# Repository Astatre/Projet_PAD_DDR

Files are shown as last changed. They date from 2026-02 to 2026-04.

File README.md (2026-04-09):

# Projet_PAD_DDR

## Description

Le projet **Projet_PAD_DDR** vise à développer un pad de jeu personnalisé, intégrant à la fois les composants matériels (hardware) et logiciels (software) nécessaires à sa réalisation. Ce pad est conçu pour être utilisé dans des jeux de rythme ou d'autres applications interactives, offrant une expérience de jeu immersive et personnalisable.

## Objectifs

- Concevoir et assembler le hardware du pad, incluant des boutons et interfaces de connexion.
- Développer le software pour gérer les entrées utilisateur, traiter les signaux et communiquer avec des appareils externes (comme un ordinateur ou une console de jeu).

## Cahier des Charges

### Fonctionnalités Requises
- **Hardware** :
    - Boutons résistants et sensibles pour une détection précise des pressions.
    - Interface de connexion USB pour une intégration facile.
    - Alimentation via câble.
- **Software** :
    - Gestion des entrées en temps réel.
    - Compatibilité avec des systèmes d'exploitation courants (Windows, Linux).

### Contraintes
- Facilité d'assemblage et de maintenance.
- Respect de l'environnement.

## Structure du Projet

- **Hardware** : Schémas et composants.
- **Software** : Code source, bibliothèques et exemples d'utilisation.
- **Modèles 3D** : Ensemble des modèles d'interrupteurs pour permettre un ajustement personnalisé.

## Installation et Utilisation

1. **Matériel** : Créer le PCB présent dans le dossier `Kicad`. (V2 : connexion USB Micro, V3 : connexion USB-C)
2. **PAD** : Suivre les différents schémas et utiliser les différents modèles pour les interrupteurs dans le dossier `Model`.
3. **Logiciel** : Cloner le dépôt et compiler le code selon les instructions dans le dossier `Cube Workspace`.
4. **Test** : Connecter le pad à votre appareil et tester les fonctionnalités.

## Contribution

Les contributions sont les bienvenues ! Veuillez soumettre des issues ou des pull requests pour améliorer le projet.

## Licence

Ce projet est sous licence [MIT](https://opensource.org/licenses/MIT).

## Auteurs

- [Drault, Sourbé, Sayavong, Dalmon] - Développeurs principaux

Pour plus d'informations, consultez les fichiers dans le dépôt.

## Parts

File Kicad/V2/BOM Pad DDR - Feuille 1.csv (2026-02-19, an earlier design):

Name | Value | Socket | Nb | Data
Resistance | 100k | 0805 | 3 | Resistance.pdf
Resistance | 4.7k | 0805 | 5 | Resistance.pdf
Resistance | 290 | 0805 | 1 | Resistance.pdf
Resistance | 140 | 0805 | 1 | Resistance.pdf
Resistance | 120 | 0805 | 1 | Resistance.pdf
Resistance | 100 | 0805 | 1 | Resistance.pdf
Resistance | R_des_cables | 0805 | 8 | Resistance.pdf
Capacitor | 1µF | 0805 | 3 | Capacitor.pdf
Capacitor | 20pF | 0805 | 2 | Capacitor.pdf
Capacitor | 100nF | 0805 | 6 | Capacitor.pdf
Capacitor | 4.7µF | 0805 | 1 | Capacitor.pdf
Capacitor | C_cable | 0805 | 4 | Capacitor.pdf
LED | Vert | 0805 | 2 | https://www.farnell.com/datasheets/2045828.pdf
LED | Rouge | 0805 | 1 | https://www.farnell.com/datasheets/2045967.pdf
USB_B_Micro | NA | Wuerth_629105150521 | 1
SWD | 2 x 7 | 1.27 mm | 1
JST | 1 x2 | 2.50 mm | 4 | ST_XH_B2B-XH-A
Pin test | 1 x 8 | 2.54 mm | 1
Pin test | 1 x 2 | 2.54 mm | 2
Transistor | BCX56 | SOT-233 | 1 | https://www.mouser.fr/datasheet/3/70/1/bcp54_bcp55_bcp56.pdf
STM | G431K6Tx | LQFP-32_7x7mm_P0.8mm | 1 | https://www.st.com/resource/en/datasheet/stm32g431k6.pdf
Cristal | 32.768kHz | 1.5 x 3.2 | 1 | 830 054 236
Regulateur | 5 / 3.3 V | SSOP5 | 1 | https://moodle.ensea.fr/pluginfile.php/10188/mod_folder/content/0/BU33SD5WG-TR.pdf?forcedownload=1
Buton | NA | 6.2 x 6.2 | 2 | https://www.we-online.com/components/products/datasheet/430182070816.pdf

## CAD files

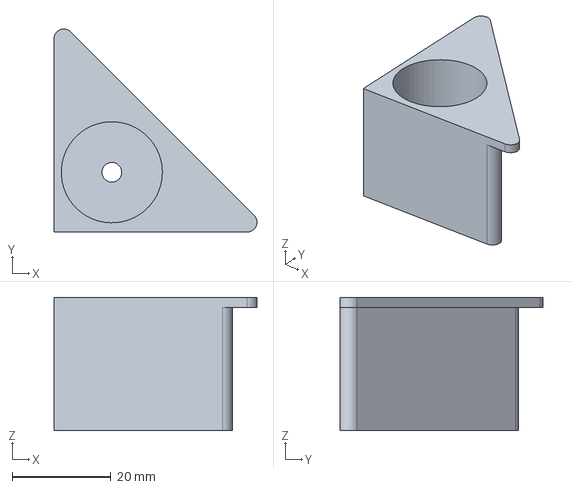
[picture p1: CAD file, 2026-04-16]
Modèles/Brackets/Brackets.FCStd
41.2 x 41.2 x 27.0 mm

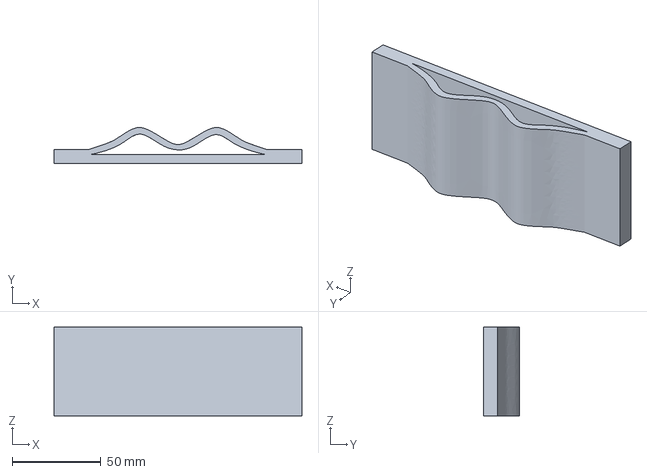
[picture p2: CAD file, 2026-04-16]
Modèles/Interrupteurs/springalt-Body.3mf
140.0 x 20.4 x 50.0 mm

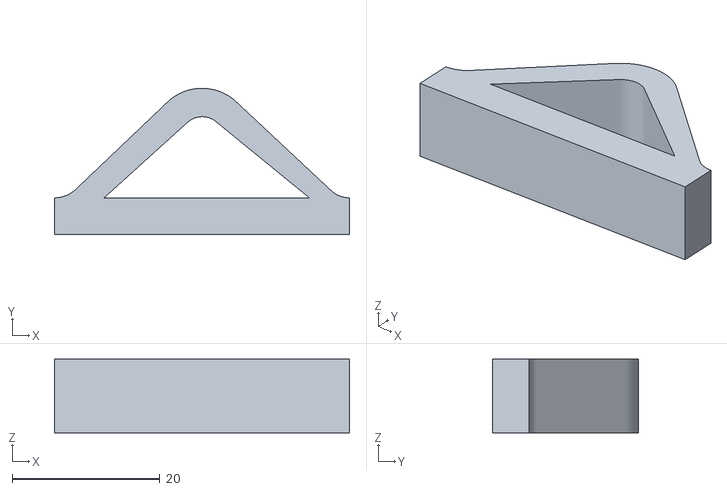
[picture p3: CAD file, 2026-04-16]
Modèles/Support coin/Support coin-Corps.stl
40.0 x 19.9 x 10.0

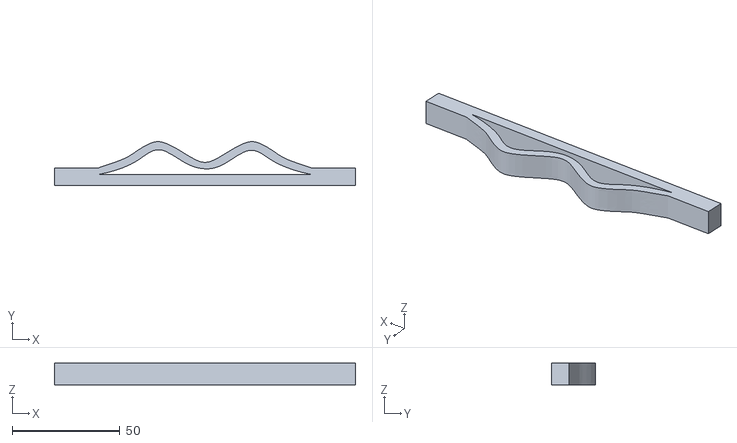
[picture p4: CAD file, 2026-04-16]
Modèles/Interrupteurs/Spring-v1.stl
140.0 x 20.4 x 10.0

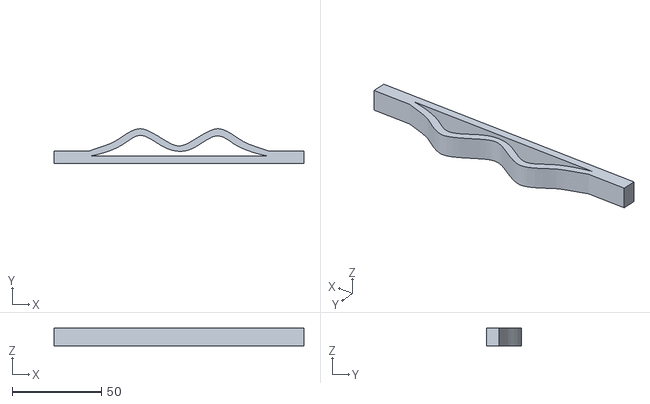
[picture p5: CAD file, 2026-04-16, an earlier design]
Modèles/Interrupteurs/Spring-v0.stl
140.0 x 19.4 x 10.0

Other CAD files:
Modèles/Support coin/Support coin.FCStd
Modèles/Interrupteurs/springalt.FCStd

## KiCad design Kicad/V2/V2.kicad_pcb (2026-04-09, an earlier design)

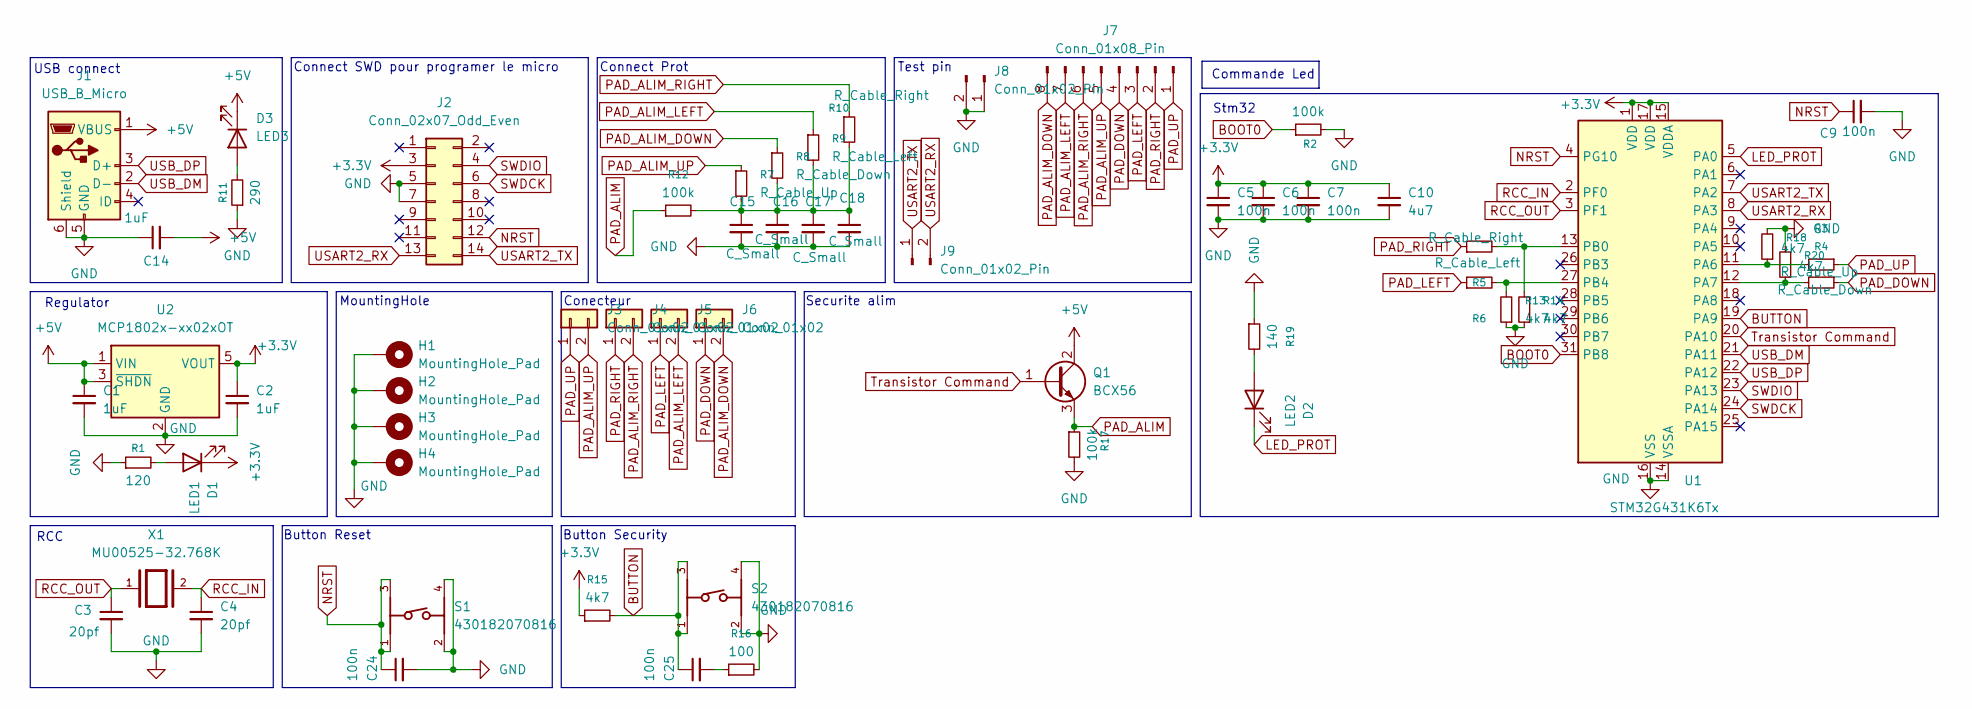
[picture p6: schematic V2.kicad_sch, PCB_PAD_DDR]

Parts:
C1, C2, C14: 1uF; C_0805_2012Metric_Pad1.18x1.45mm_HandSolder
C3, C4: 20pf; C_0805_2012Metric_Pad1.18x1.45mm_HandSolder
C5, C6, C7, C9, C24, C25: 100n; C_0805_2012Metric_Pad1.18x1.45mm_HandSolder
C10: 4u7; C_0805_2012Metric_Pad1.18x1.45mm_HandSolder
C15, C16, C17, C18: C_Small; C_0805_2012Metric_Pad1.18x1.45mm_HandSolder
D1: LED1; LED_0805_2012Metric_Pad1.15x1.40mm_HandSolder
D2: LED2; LED_0805_2012Metric_Pad1.15x1.40mm_HandSolder
D3: LED3; LED_0805_2012Metric_Pad1.15x1.40mm_HandSolder
H1, H2, H3, H4: MountingHole_Pad; MountingHole_3.2mm_M3_DIN965_Pad
J1: USB_B_Micro; USB_Micro-B_Wuerth_629105150521
J2: Conn_02x07_Odd_Even; PinHeader_2x07_P1.27mm_Vertical_SMD
J3, J4, J5, J6: Conn_01x02; JST_XH_B2B-XH-A_1x02_P2.50mm_Vertical
J7: Conn_01x08_Pin; PinHeader_1x08_P2.54mm_Vertical
J8, J9: Conn_01x02_Pin; PinHeader_1x02_P2.54mm_Vertical
Q1: BCX56; SOT-223
R1: 120; R_0805_2012Metric_Pad1.20x1.40mm_HandSolder
R2, R12, R17: 100k; R_0805_2012Metric_Pad1.20x1.40mm_HandSolder
R3, R7: R_Cable_Up; R_0805_2012Metric_Pad1.20x1.40mm_HandSolder
R4, R8: R_Cable_Down; R_0805_2012Metric_Pad1.20x1.40mm_HandSolder
R5, R10: R_Cable_Right; R_0805_2012Metric_Pad1.20x1.40mm_HandSolder
R6, R9: R_Cable_Left; R_0805_2012Metric_Pad1.20x1.40mm_HandSolder
R11: 290; R_0805_2012Metric_Pad1.20x1.40mm_HandSolder
R13, R14, R15, R18, R20: 4k7; R_0805_2012Metric_Pad1.20x1.40mm_HandSolder
R16: 100; R_0805_2012Metric_Pad1.20x1.40mm_HandSolder
R19: 140; R_0805_2012Metric_Pad1.20x1.40mm_HandSolder
S1, S2: 430182070816
U1: STM32G431K6Tx; LQFP-32_7x7mm_P0.8mm
U2: MCP1802x-xx02xOT; SOT-23-5
X1: MU00525-32.768K; XTAL_MU00525-32.768K

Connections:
Transistor Command: Q1.1 (B), U1.20 (PA10)
+3.3V: C2.1, C5.1, C6.1, C7.1, C10.1, D1.1 (K), J2.3, R15.1, U1.1 (VDD), U1.15 (VDDA), U1.17 (VDD), U2.5 (VOUT)
+5V: C1.1, C14.2, D3.1 (K), J1.1 (VBUS), Q1.2 (C), U2.1 (VIN), U2.3 (~SHDN)
BOOT0: R2.1, U1.31 (PB8)
BUTTON: C25.1, R15.2, S2.1, S2.3, U1.19 (PA9)
GND: C1.2, C2.2, C3.2, C4.2, C5.2, C6.2, C7.2, C9.2, C10.2, C14.1, C15.2, C16.2, C17.2, C18.2, C24.2, H1.1, H2.1, H3.1, H4.1, J1.5 (GND), J1.6 (Shield), J2.5, J2.7, J8.1, J8.2, R1.1, R2.2, R11.1, R13.1, R14.1, R16.2, R17.2, R18.2, R19.1, R20.2, S1.2, S1.4, S2.2, S2.4, U1.14 (VSSA), U1.16 (VSS), U1.32 (VSS), U2.2 (GND)
LED_PROT: D2.1 (K), U1.5 (PA0)
NRST: C9.1, C24.1, J2.12, S1.1, S1.3, U1.4 (PG10)
unnamed: C15.1, C16.1, C17.1, C18.1, R7.2, R8.2, R9.2, R10.2, R12.2
unnamed: C25.2, R16.1
unnamed: D1.2 (A), R1.2
unnamed: D2.2 (A), R19.2
unnamed: D3.2 (A), R11.2
unnamed: R3.2, R18.1, U1.11 (PA6)
unnamed: R4.2, R20.1, U1.12 (PA7)
unnamed: R5.2, R14.2, U1.13 (PB0)
unnamed: R6.2, R13.2, U1.27 (PB4)
PAD_ALIM: Q1.3 (E), R12.1, R17.1
PAD_ALIM_DOWN: J6.2, J7.8, R8.1
PAD_ALIM_LEFT: J5.2, J7.7, R9.1
PAD_ALIM_RIGHT: J4.2, J7.6, R10.1
PAD_ALIM_UP: J3.2, J7.5, R7.1
PAD_DOWN: J6.1, J7.4, R4.1
PAD_LEFT: J5.1, J7.3, R6.1
PAD_RIGHT: J4.1, J7.2, R5.1
PAD_UP: J3.1, J7.1, R3.1
RCC_IN: C4.1, U1.2 (PF0), X1.2
RCC_OUT: C3.1, U1.3 (PF1), X1.1
SWDCK: J2.6, U1.24 (PA14)
SWDIO: J2.4, U1.23 (PA13)
USART2_RX: J2.13, J9.2, U1.8 (PA3)
USART2_TX: J2.14, J9.1, U1.7 (PA2)
USB_DM: J1.2 (D-), U1.21 (PA11)
USB_DP: J1.3 (D+), U1.22 (PA12)

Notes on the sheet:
Securite alim
Regulator
Commande Led
MountingHole
Stm32
Test pin
USB connect
Connect SWD pour programer le micro
Button Security
Button Reset
RCC
Conecteur
Connect Prot

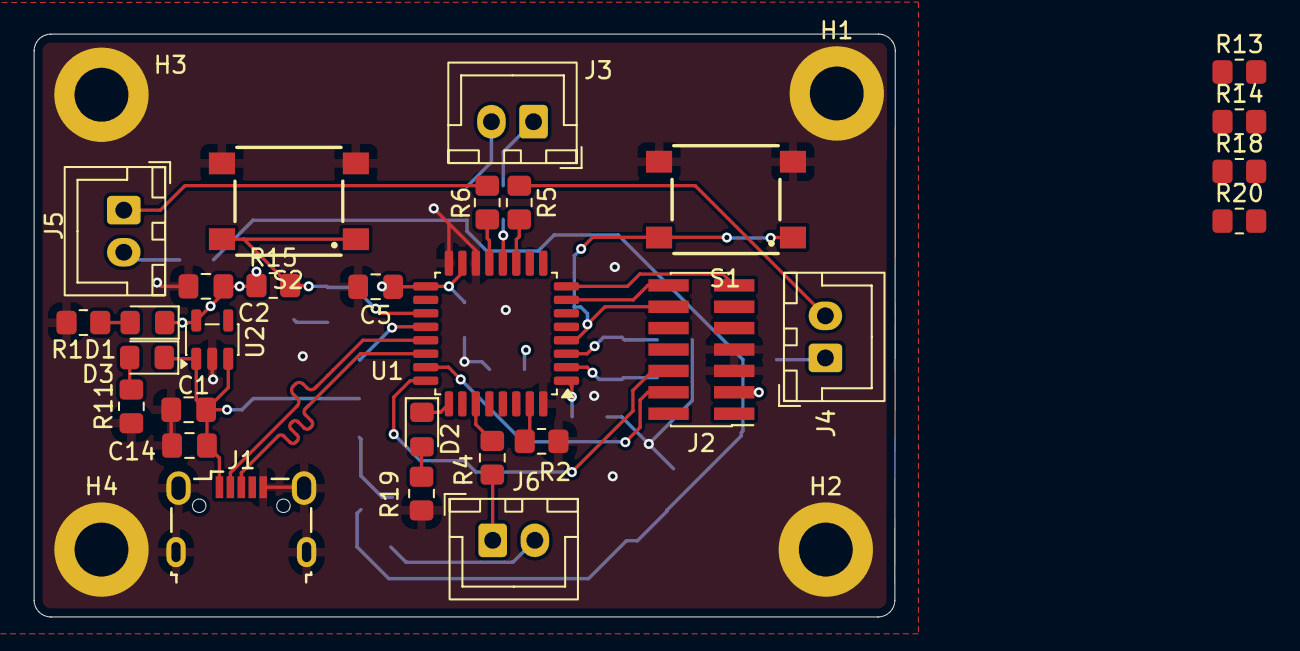
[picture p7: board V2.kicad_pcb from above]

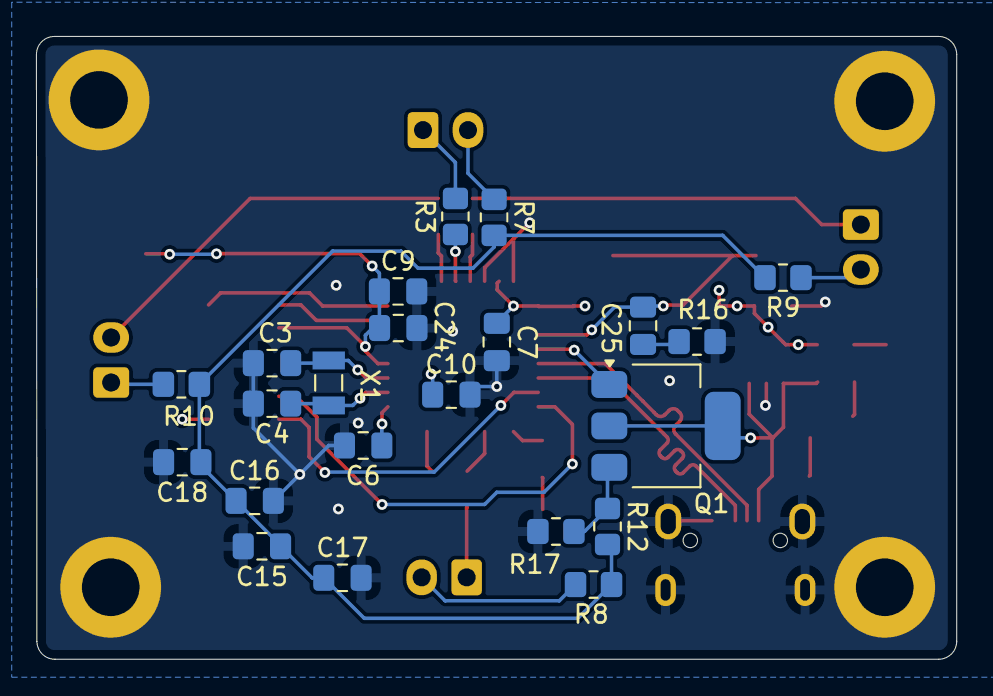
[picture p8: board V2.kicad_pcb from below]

Board: 4 copper layers, 51.1 x 34.6 mm, 55 parts (22 on the bottom side), 34 nets.

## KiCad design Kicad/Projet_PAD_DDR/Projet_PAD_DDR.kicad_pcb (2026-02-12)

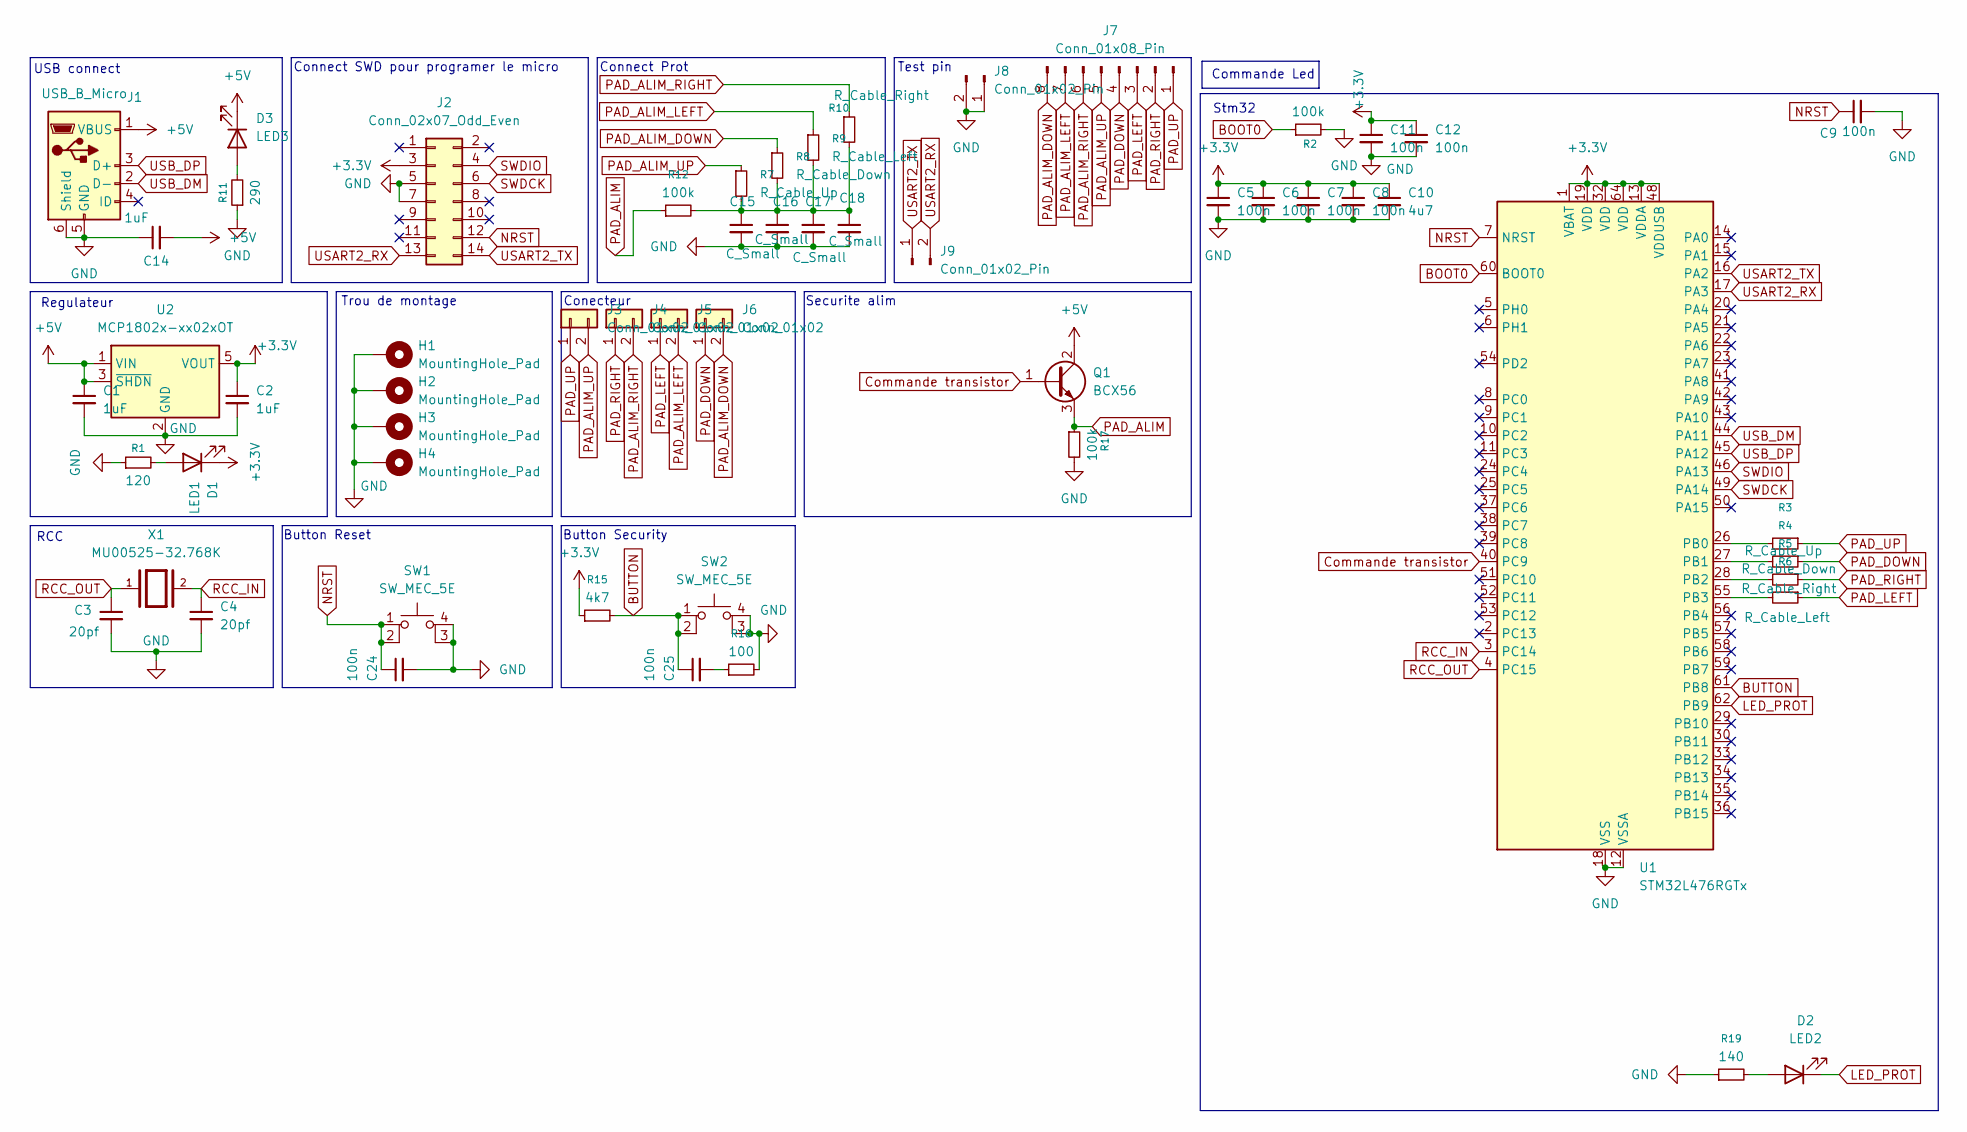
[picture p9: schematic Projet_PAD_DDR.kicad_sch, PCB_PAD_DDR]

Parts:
C1, C2, C14: 1uF; C_0805_2012Metric_Pad1.18x1.45mm_HandSolder
C3, C4: 20pf; C_0805_2012Metric_Pad1.18x1.45mm_HandSolder
C5, C6, C7, C8, C9, C11, C12, C24, C25: 100n; C_0805_2012Metric_Pad1.18x1.45mm_HandSolder
C10: 4u7; C_0805_2012Metric_Pad1.18x1.45mm_HandSolder
C15, C16, C17, C18: C_Small; C_0805_2012Metric_Pad1.18x1.45mm_HandSolder
D1: LED1; LED_0805_2012Metric_Pad1.15x1.40mm_HandSolder
D2: LED2; LED_0805_2012Metric_Pad1.15x1.40mm_HandSolder
D3: LED3; LED_0805_2012Metric_Pad1.15x1.40mm_HandSolder
H1, H2, H3, H4: MountingHole_Pad; MountingHole_3.2mm_M3_DIN965_Pad
J1: USB_B_Micro; USB_Micro-B_Wuerth_629105150521
J2: Conn_02x07_Odd_Even; PinHeader_2x07_P1.27mm_Vertical_SMD
J3, J4, J5, J6: Conn_01x02; JST_XH_B2B-XH-A_1x02_P2.50mm_Vertical
J7: Conn_01x08_Pin; PinHeader_1x08_P2.54mm_Vertical
J8, J9: Conn_01x02_Pin; PinHeader_1x02_P2.54mm_Vertical
Q1: BCX56; SOT-223
R1: 120; R_0805_2012Metric_Pad1.20x1.40mm_HandSolder
R2, R12, R17: 100k; R_0805_2012Metric_Pad1.20x1.40mm_HandSolder
R3, R7: R_Cable_Up; R_0805_2012Metric_Pad1.20x1.40mm_HandSolder
R4, R8: R_Cable_Down; R_0805_2012Metric_Pad1.20x1.40mm_HandSolder
R5, R10: R_Cable_Right; R_0805_2012Metric_Pad1.20x1.40mm_HandSolder
R6, R9: R_Cable_Left; R_0805_2012Metric_Pad1.20x1.40mm_HandSolder
R11: 290; R_0805_2012Metric_Pad1.20x1.40mm_HandSolder
R15: 4k7; R_0805_2012Metric_Pad1.20x1.40mm_HandSolder
R16: 100; R_0805_2012Metric_Pad1.20x1.40mm_HandSolder
R19: 140; R_0805_2012Metric_Pad1.20x1.40mm_HandSolder
SW1, SW2: SW_MEC_5E; SW_MEC_5GSH9
U1: STM32L476RGTx; LQFP-64_10x10mm_P0.5mm
U2: MCP1802x-xx02xOT; SOT-23-5
X1: MU00525-32.768K; XTAL_MU00525-32.768K

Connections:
+3.3V: C2.1, C5.1, C6.1, C7.1, C8.1, C10.1, C11.1, C12.1, D1.1 (K), J2.3, R15.1, U1.1 (VBAT), U1.13 (VDDA), U1.19 (VDD), U1.32 (VDD), U1.48 (VDDUSB), U1.64 (VDD), U2.5 (VOUT)
+5V: C1.1, C14.2, D3.1 (K), J1.1 (VBUS), Q1.2 (C), Q1.4, U2.1 (VIN), U2.3 (~SHDN)
BOOT0: R2.1, U1.60 (BOOT0)
BUTTON: C25.1, R15.2, SW2.1, SW2.2, U1.61 (PB8)
Commande transistor: Q1.1 (B), U1.40 (PC9)
GND: C1.2, C2.2, C3.2, C4.2, C5.2, C6.2, C7.2, C8.2, C9.2, C10.2, C11.2, C12.2, C14.1, C15.2, C16.2, C17.2, C18.2, C24.2, H1.1, H2.1, H3.1, H4.1, J1.5 (GND), J1.6 (Shield), J2.5, J2.7, J8.1, J8.2, R1.1, R2.2, R11.1, R16.2, R17.2, R19.1, SW1.3 (K), SW1.4 (A), SW2.3 (K), SW2.4 (A), U1.12 (VSSA), U1.18 (VSS), U1.31 (VSS), U1.47 (VSS), U1.63 (VSS), U2.2 (GND)
LED_PROT: D2.1 (K), U1.62 (PB9)
NRST: C9.1, C24.1, J2.12, SW1.1, SW1.2, U1.7 (NRST)
unnamed: C15.1, C16.1, C17.1, C18.1, R7.2, R8.2, R9.2, R10.2, R12.2
unnamed: C25.2, R16.1
unnamed: D1.2 (A), R1.2
unnamed: D2.2 (A), R19.2
unnamed: D3.2 (A), R11.2
unnamed: R3.2, U1.26 (PB0)
unnamed: R4.2, U1.27 (PB1)
unnamed: R5.2, U1.28 (PB2)
unnamed: R6.2, U1.55 (PB3)
PAD_ALIM: Q1.3 (E), R12.1, R17.1
PAD_ALIM_DOWN: J6.2, J7.8, R8.1
PAD_ALIM_LEFT: J5.2, J7.7, R9.1
PAD_ALIM_RIGHT: J4.2, J7.6, R10.1
PAD_ALIM_UP: J3.2, J7.5, R7.1
PAD_DOWN: J6.1, J7.4, R4.1
PAD_LEFT: J5.1, J7.3, R6.1
PAD_RIGHT: J4.1, J7.2, R5.1
PAD_UP: J3.1, J7.1, R3.1
RCC_IN: C4.1, U1.3 (PC14), X1.2
RCC_OUT: C3.1, U1.4 (PC15), X1.1
SWDCK: J2.6, U1.49 (PA14)
SWDIO: J2.4, U1.46 (PA13)
USART2_RX: J2.13, J9.2, U1.17 (PA3)
USART2_TX: J2.14, J9.1, U1.16 (PA2)
USB_DM: J1.2 (D-), U1.44 (PA11)
USB_DP: J1.3 (D+), U1.45 (PA12)

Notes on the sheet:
Securite alim
Regulateur
Commande Led
Trou de montage
Stm32
Test pin
USB connect
Connect SWD pour programer le micro
Button Security
Button Reset
RCC
Conecteur
Connect Prot

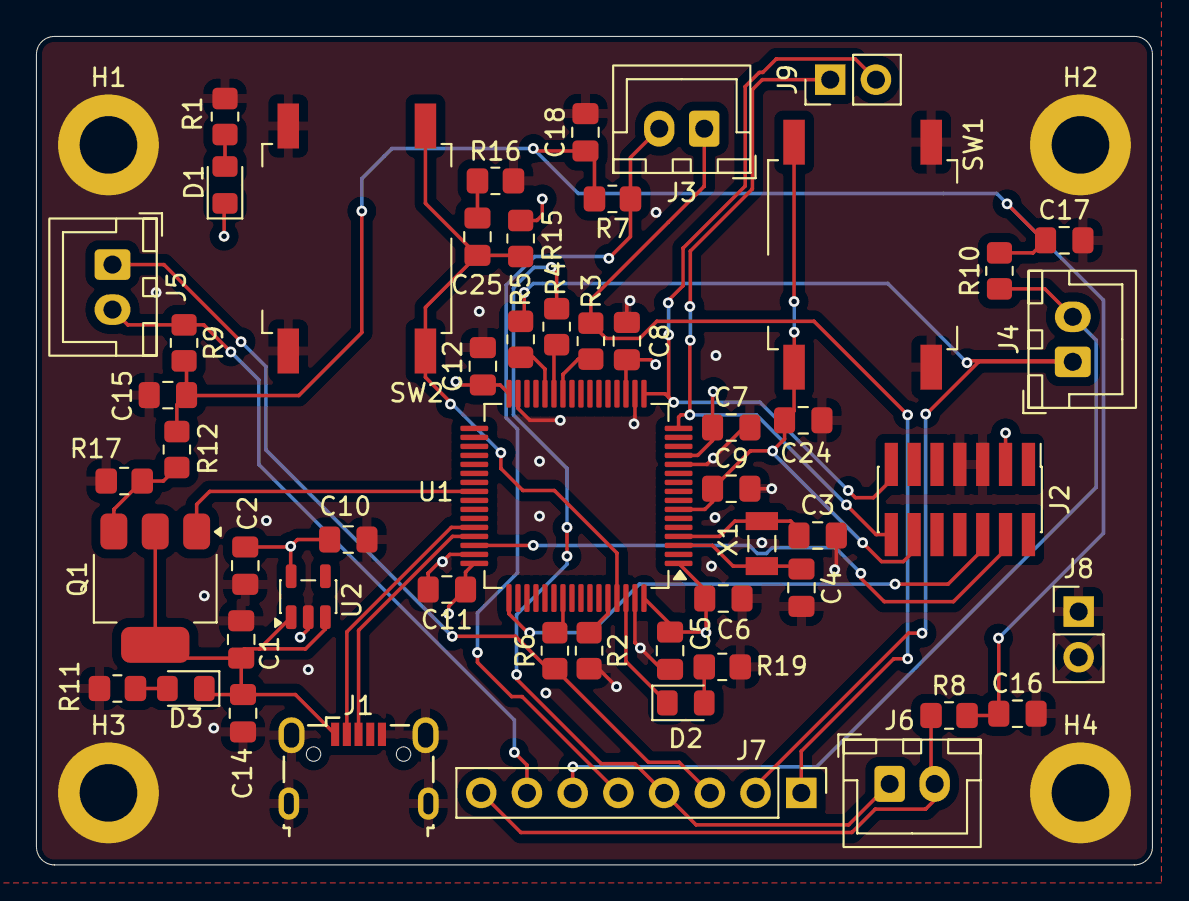
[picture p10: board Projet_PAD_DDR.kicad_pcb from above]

Board: 4 copper layers, 62.0 x 46.0 mm, 57 parts (0 on the bottom side), 34 nets.

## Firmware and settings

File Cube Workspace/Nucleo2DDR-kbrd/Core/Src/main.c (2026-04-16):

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
/* Includes ------------------------------------------------------------------*/
#include "main.h"
#include "usb_device.h"

/* USER CODE BEGIN Includes */
#include "usbd_customhid.h"
/* USER CODE END Includes */

/* USER CODE BEGIN PD */
//Définition des codes des touches
#define KEY_UP    0x52
#define KEY_DOWN  0x51
#define KEY_RIGHT 0x4F
#define KEY_LEFT  0x50
/* USER CODE END PD */

UART_HandleTypeDef huart2;

/* USER CODE BEGIN PV */
extern USBD_HandleTypeDef hUsbDeviceFS;	// Canal pour la communication USB
uint8_t keyboardReport[8] = {0};		// Buffer de 8 octets pour le rapport USB à envoyer
volatile uint8_t event_detected = 0;	// Signaler un changement d'état
/* USER CODE END PV */

void SystemClock_Config(void);
static void MX_GPIO_Init(void);
static void MX_USART2_UART_Init(void);
/**
  * @brief  The application entry point.
  * @retval int
  */
int main(void)
{

  /* MCU Configuration--------------------------------------------------------*/

  /* Reset of all peripherals, Initializes the Flash interface and the Systick. */
  HAL_Init();

  /* Configure the system clock */
  SystemClock_Config();

  /* Initialize all configured peripherals */
  MX_GPIO_Init();
  MX_USART2_UART_Init();
  MX_USB_DEVICE_Init();
  /* Infinite loop */
  /* USER CODE BEGIN WHILE */
  while (1)
  {
    /* USER CODE END WHILE */

    /* USER CODE BEGIN 3 */
	  if (event_detected){
	      HAL_Delay(20); // Anti-rebond basique
	      for (int i = 2; i < 8; i++) keyboardReport[i] = (int) NULL;

	      uint8_t key_index = 2;

	      // Vérification indépendante de chaque touche
	      if (HAL_GPIO_ReadPin(GPIOB, GPIO_PIN_0) == GPIO_PIN_RESET) {
	          keyboardReport[key_index++] = KEY_UP;
	      }
	      if (HAL_GPIO_ReadPin(GPIOB, GPIO_PIN_1) == GPIO_PIN_RESET) {
	          keyboardReport[key_index++] = KEY_DOWN;
	      }
	      if (HAL_GPIO_ReadPin(GPIOB, GPIO_PIN_2) == GPIO_PIN_RESET) {
	          keyboardReport[key_index++] = KEY_RIGHT;
	      }
	      if (HAL_GPIO_ReadPin(GPIOB, GPIO_PIN_3) == GPIO_PIN_RESET) {
	          keyboardReport[key_index++] = KEY_LEFT;
	      }

	      USBD_CUSTOM_HID_SendReport(&hUsbDeviceFS, keyboardReport, 8);
	      event_detected = 0;
	      if(keyboardReport[2]==(int)NULL){
		  	  HAL_GPIO_WritePin(GPIOA, GPIO_PIN_5, GPIO_PIN_RESET);
	      }
	      HAL_Delay(5);
	  }
  }
  /* USER CODE END 3 */
}

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
/* USER CODE BEGIN 4 */
void HAL_GPIO_EXTI_Callback(uint16_t GPIO_Pin)
{
    if (GPIO_Pin == GPIO_PIN_0 || GPIO_Pin == GPIO_PIN_1 || GPIO_Pin == GPIO_PIN_2 || GPIO_Pin == GPIO_PIN_3){
        event_detected = 1;
        HAL_GPIO_WritePin(GPIOA, GPIO_PIN_5, GPIO_PIN_SET);
    }
}
/* USER CODE END 4 */
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


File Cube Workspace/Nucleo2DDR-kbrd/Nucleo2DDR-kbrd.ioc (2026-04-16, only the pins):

Mcu.UserName=STM32L476RGTx
PA11.Signal=USB_OTG_FS_DM
PA12.Signal=USB_OTG_FS_DP
PA2.Signal=USART2_TX
PA3.Signal=USART2_RX
PA5.GPIO_Label=L2_User
PA5.Signal=GPIO_Output
PB0.GPIO_Label=UP
PB0.Signal=GPXTI0
PB1.GPIO_Label=DOWN
PB1.Signal=GPXTI1
PB2.GPIO_Label=RIGHT
PB2.Signal=GPXTI2
PB9.GPIO_Label=LED
PB9.Signal=GPIO_Output

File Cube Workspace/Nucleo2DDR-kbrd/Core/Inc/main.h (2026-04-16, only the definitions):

#define L2_User_Pin GPIO_PIN_5
#define L2_User_GPIO_Port GPIOA
#define UP_Pin GPIO_PIN_0
#define UP_GPIO_Port GPIOB
#define UP_EXTI_IRQn EXTI0_IRQn
#define DOWN_Pin GPIO_PIN_1
#define DOWN_GPIO_Port GPIOB
#define DOWN_EXTI_IRQn EXTI1_IRQn
#define RIGHT_Pin GPIO_PIN_2
#define RIGHT_GPIO_Port GPIOB
#define RIGHT_EXTI_IRQn EXTI2_IRQn
#define LEFT_Pin GPIO_PIN_3
#define LEFT_GPIO_Port GPIOB
#define LEFT_EXTI_IRQn EXTI3_IRQn
#define LED_Pin GPIO_PIN_9
#define LED_GPIO_Port GPIOB

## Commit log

2026-02-08 First Schematic
    Besoin de dimensionné les composant et de choisir les led.
    [Projet_PAD_DDR.kicad_sch]
2026-02-12 Version test première verification
    [Projet_PAD_DDR.kicad_pcb, Projet_PAD_DDRV0.5.kicad_sch]
2026-02-12 Version a verifier
    [Projet_PAD_DDR.kicad_pcb, Projet_PAD_DDR.kicad_sch]
2026-02-16 La v2 avec un autre Mc
    [V2.kicad_pcb, V2.kicad_sch]
2026-02-19 Kicad a verif
    [V2.kicad_pcb, V2.kicad_sch]
2026-02-19 Changement detaille de piste
    [V2.kicad_pcb]
2026-02-21 Ajout des projets Cube pour la Nucleo
2026-02-21 Revert "Ajout des projets Cube pour la Nucleo"
    This reverts commit 23604323aca1d2e4fba32a353018f6e3ff98db90.
    [Nucleo2DDR-kbrd.ioc, Nucleo2Keyboard.ioc, Nucleo2Mouse.ioc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]
2026-02-21 Correction de l'ajout des projets Cube pour la Nucleo
    [Nucleo2DDR-kbrd.ioc, Nucleo2Keyboard.ioc, Nucleo2Mouse.ioc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]
2026-03-18 Added springs stl
    [Spring-v0.stl, Spring-v1.stl]
2026-03-18 Réorganisation des fichiers
    [Spring-v0.stl, Spring-v1.stl, springalt.FCStd]
2026-03-18 Réorganisation des fichiers et ajout du fichier CAD
    [Spring-v0.stl, Spring-v1.stl]
2026-03-19 Ajout v3
    [V3.kicad_pcb, V3.kicad_sch]
2026-03-26 Version final
    [V3.kicad_pcb, V3.kicad_sch]
2026-03-26 Version final + seri
    [V3.kicad_pcb, V3.kicad_sch]
2026-04-09 Version merge
    [BOM Pad DDR - Feuille 1.csv, Projet_PAD_DDR.kicad_pcb, Projet_PAD_DDR.kicad_sch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]
2026-04-13 Ajout des autres pièces
    [Brackets.FCStd, Spring-v0.stl, Spring-v1.stl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]
2026-04-13 Suppression des anciens fichiers
    [Spring-v0.stl, Spring-v1.stl, springalt.FCStd]
2026-04-16 Revert "Merge branch 'Modèles-3D'"
    This reverts commit f74af3508975ee8b5dad27d226e8cc0d71e5569e, reversing
    changes made to eb41a01a9987be4433b5e7c587b1462da7b78b96.
    [Spring-v0.stl, Spring-v1.stl, springalt.FCStd]

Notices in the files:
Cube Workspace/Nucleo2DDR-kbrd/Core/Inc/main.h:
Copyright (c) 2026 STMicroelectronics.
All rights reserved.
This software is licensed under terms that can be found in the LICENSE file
